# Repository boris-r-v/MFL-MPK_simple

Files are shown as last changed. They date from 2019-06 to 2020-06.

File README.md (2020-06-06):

# MFL-MPK_simple
Модем работающий по 2-х проводной физической линии связи на базе микросхемы FX604D4 - V23 совместимым модемом

**Задачи**
        
        Принять пакет данных по кодовой линии RS-232/485 и переслать этот пакет данных по физической линии
        Приянть пакет из физической линии и переслать на последовательный интерфейс RS-232/485
        
*Информация от уволившегося разработчика*

        MFL-MPK_simple

        Модем по RS-232 и RS-485 может работать на 4 скоростях: 19200, 38400, 57600, 115200. Скорость задается двумя битами на переключателе (вроде 7 и 8 переключатели). Остальные 6 переключателей – адрес модема. RS-232 и RS-485 работают одновременно.

        Запрос адреса: в RS-232 двумя байтами – 0x14, 0xFF. Ответ, два байта: 0xEB, 0x(адрес).

        Формат кадра на линии: 
            1) Заголовок (4 байта): 0x55, 0x(ст. байт размера данных), 0x(мл. байт размера данных), 0x(CRC8 заголовка)
            2) Данные из RS-485 и RS-232.

            В проекте гитигнор неправильно прописан, поэтому куча мусора. Зато в MFL-MPK_simple/dist/default/production есть hex-файл, он должен быть рабочим. Можно им прошить модем и проверить на стенде.

            Насчет коэф. усиления в линии. В его регулировке смысла не увидел, на макете линии в довольно больших диапазонах ее длины норм работает (до 8 км смотрел при самой плохой линии). Можно еще раз испытать. Сори, не помню и никуда не записал, какой поставил резистор (который задает коэф усил) на промышленной. Вроде 10 (или 100) кОм. Лучше проверить.

            Сама прошивка работает по принципу: от прерывания запускается процесс приема из линии (RS) и после приема сразу передается в RS (линию). line_to_RS и RS_to_line соответственно.

            Прошу еще раз проверить работу.

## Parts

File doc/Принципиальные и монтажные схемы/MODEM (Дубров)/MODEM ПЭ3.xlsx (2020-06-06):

Поз.обозначение | Наименование |  | Кол-во | Примечание
 | Конденсаторы
C1, C2 | К73-17-400-1.5 10% имп. | TS0200(2G155K)SB0G0R P:22.5mm | 2
C3 | CC0805KRX7R9BB154 | 0805 X7R 0.15uF ±10% 50V | 1
C4, C5 | CC1206KKX7R8BB225 | 1206 X7R 2.2uF ±10% 25V | 2
C6 | CC0805JRNPO9BN101 | 0805 NP0 100pF ±5% 50V | 1
C7, C17, C20 | T491B106K016AT | чип тант.16В 10мкФ 10% B | 3
C8, C9 | CC0805JRNPO9BN200 | 0805 NP0 20pF ±5% 50V | 2
C11-C16, C18, C19, C21-C29, C32, C34, C36 | CC0805ZRY5V9BB104 | 0805 Y5V 0.1uF +80/-20% 50V | 20
C31 | SH050M0220B5S-1012 | 50V 220uF /10*12/105° | 1
C35 | T491D476K025AT | чип тант.25В 47мкФ 10% D | 1
 | Микросхемы
DA1 | LM258DT |  | 1
DA2 | MC78L08ABDR2G |  | 1
DA3 | L78L33ABD |  | 1
DA4 | TEN 3-2413WIN-HI |  | 1
DD1 | FX604D4 |  | 1
DD2 | CMX868D2 |  | 1
DD3 | PIC24HJ128GP502 |  | 1
DD4, DD5 | ST3485EBDR |  | 2
DD6 | ST3232BDR |  | 1
DD7 | SN74HC165D |  | 1
 | Диоды
HL1, HL2, HL3 | KP-3216EC |  | 3
VD1 | SM6T6V8CA |  | 1
VD2 | BAV199 |  | 1
VD3, VD4 | SMAJ15CA |  | 2
VD5-VD10 | SMAJ5.0CA |  | 6
VD11 | SS14 |  | 1
VD12 | SMCJ30CA |  | 1
 | Транзисторы
VT1, VT2 | BCR135E6327 |  | 2
 | Резисторы
R1 | RC1206FR-07200RL | 1206 200 1% | 1
R2 | RC0805FR-0727KL | 0805 27.0K 1% | 1
R3, R7 | RC0805FR-0747K5L | 0805 47.5K 1% | 2
R4, R8 | RC0805FR-0724KL | 0805 24.0K 1% | 2
R5, R9 | RC0805FR-0712KL | 0805 12.0K 1% | 2
R6, R10 | RC0805FR-076K04L | 0805 6.04K 1% | 2
R11, R23-R31 | RC0805FR-0747KL | 0805 47.0K 1% | 10
R12 | RC0805FR-07150KL | 0805 150K 1% | 1
R13 | RC0805FR-07100KL | 0805 100K 1% | 1
R14, R15 | RC0805FR-07180RL | 0805 180 1% | 2
R16, R18, R19, R21 | RC0805FR-07560RL | 0805 560 1% | 4
R17, R20 | RC0805FR-07120RL | 0805 120 1% | 2
R22 | RC1206FR-071K5L | 1206 1.50K 1% | 1
RV1 | JVR10N180M87PU5 |  | 1
RV2 | JVR10N390K87PU5 |  | 1
 | Коммутация
SA1, SA2 | DHN-08F-V |  | 2
X1, X2 | 25.338.3753.0 | 8113_S/07 | 2
X1', X2' | 25.322.3753.0 | 8113_S/07 | 2
X3 | PLS-06 |  | 1
X4 | PBS-12 |  | 1
X4' | PLH-12-15mm |  | 1 | PLH-40-15mm
 | Прочее
FU1 | TRF250-120 |  | 1
FU2 | RXEF075 |  | 1
L1, L2 | MMZ2012Y202B |  | 2
L3, L4 | DLW5BTN102SQ2L |  | 2
L5 | UU10LF-B682 | 6.8mH 0.43A | 1
TV1 | LM-NP-1001-B1L |  | 1
ZQ1 | 3.579545 MHz | HC-49/US | 1 | ЧИП И ДИП

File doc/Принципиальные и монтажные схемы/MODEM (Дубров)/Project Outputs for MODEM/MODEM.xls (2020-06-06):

Comment | Description | Designator | Footprint | LibRef | Quantity
1.5uF |  | C1, C2 | TS02-22.5 | CC1206 | 2.0
0.15uF |  | C3 | CC0805 | CC1206 | 1.0
1.5uF |  | C4, C5 | CC1206 | CC1206 | 2.0
100pF |  | C6 | CC0805 | CC1206 | 1.0
10uF |  | C7, C17, C20 | SMB | SR-6 | 3.0
20pF |  | C8, C9 | CC0805 | CC1206 | 2.0
0.1uF |  | C11, C12, C13, C14, C15, C16, C18, C19, C21, C22, C23, C24, C25, C26, C27, C28, C29, C32, C34, C36 | CC0805 | CC1206 | 20.0
SH050M0220B5S-1012 |  | C31 | SH050-1019 | SR-6 | 1.0
47uF |  | C35 | SMD | SR-6 | 1.0
LM258DT |  | DA1 | LM258DT | LM258DT | 1.0
MC78L08ABDR2G |  | DA2 | L78L06ABD | L78L06ABD | 1.0
L78L33ABD |  | DA3 | L78L06ABD | L78L33ABD | 1.0
TEN 3-2413WIN-HI |  | DA4 | TEN3-2412WIN | TEN3-2412WIN | 1.0
FX604D4 |  | DD1 | FX604D4 | FX604D4 | 1.0
CMX868D2 |  | DD2 | CMX868D2 | CMX868D2 | 1.0
PIC24HJ128GP502 |  | DD3 | PIC24HJ128GP502 | PIC24HJ128GP502 | 1.0
ST3485 |  | DD4, DD5 | SP3485 | SP3485 | 2.0
ST3232BDR |  | DD6 | ST3232BDR | SP3232 | 1.0
SN74HC165D |  | DD7 | SN74HC165D | SN74HC165D | 1.0
TRF250-120 |  | FU1 | TRF250-120 | TRF250-120 | 1.0
RXEF075 |  | FU2 | RXEF075 | TRF250-120 | 1.0
KP-3216EC |  | HL1, HL2, HL3 | KP-3216EC | KP-3216EC_L | 3.0
MMZ2012Y202B |  | L1, L2 | MMZ2012Y202B | MMZ2012Y202B | 2.0
DLW5BTN102SQ2L |  | L3, L4 | DLW5BTN | DLW31SN | 2.0
UU10LF |  | L5 | UU10LF | TRANS | 1.0
200 |  | R1 | RC1206 | RC1206 | 1.0
27K |  | R2 | RC0805 | RC0805 | 1.0
47.5K |  | R3, R7 | RC0805 | RC0805 | 2.0
24K |  | R4, R8 | RC0805 | RC0805 | 2.0
12K |  | R5, R9 | RC0805 | RC0805 | 2.0
6.04K |  | R6, R10 | RC0805 | RC0805 | 2.0
47K |  | R11, R23, R24, R25, R26, R27, R28, R29, R30, R31 | RC0805 | RC0805 | 10.0
150K |  | R12 | RC0805 | RC0805 | 1.0
100K |  | R13 | RC0805 | RC0805 | 1.0
180 |  | R14, R15 | RC0805 | RC0805 | 2.0
560 |  | R16, R18, R19, R21 | RC0805 | RC0805 | 4.0
120 |  | R17, R20 | RC0805 | RC0805 | 2.0
1.5K |  | R22 | RC1206 | RC0805 | 1.0
JVR10N180M87PU5 |  | RV1 | JVR07N330 | JVR14N361 | 1.0
JVR10N390K87PU5 |  | RV2 | JVR07N330 | JVR14N361 | 1.0
DHN-08F-V |  | SA1, SA2 | DHN-08F-V | DHN-08F-V | 2.0
LM-NP-1001 |  | TV1 | LM-NP-1001 | LM-NP-1001 | 1.0
SM6T6V8CA |  | VD1 | SM6T6V8CA | SM6T6V8CA | 1.0
BAV199 |  | VD2 | BAV199 | BAV199 | 1.0
SMAJ15CA |  | VD3, VD4 | SMAJ6.0CA | SMAJ6.0CA | 2.0
SMAJ5.0CA |  | VD5, VD6, VD7, VD8, VD9, VD10 | SMAJ6.0CA | SMAJ6.0CA | 6.0
SS14 |  | VD11 | SS14 | SS14 | 1.0
SMCJ30CA |  | VD12 | SMCJ28A | SM6T6V8CA | 1.0
BCR135 |  | VT1, VT2 | BCR135 | BCR135 | 2.0
8113_S/07 |  | X1, X2 | 8113_S/07 | 8113_S/07 | 2.0
PLS-06 |  | X3 | PLS-06 | PLS-06 | 1.0
PLS-12 |  | X4 | PLS-12 | PLS-12 | 2.0
3.58M |  | ZQ1 | HC-49/S | ZQ | 1.0

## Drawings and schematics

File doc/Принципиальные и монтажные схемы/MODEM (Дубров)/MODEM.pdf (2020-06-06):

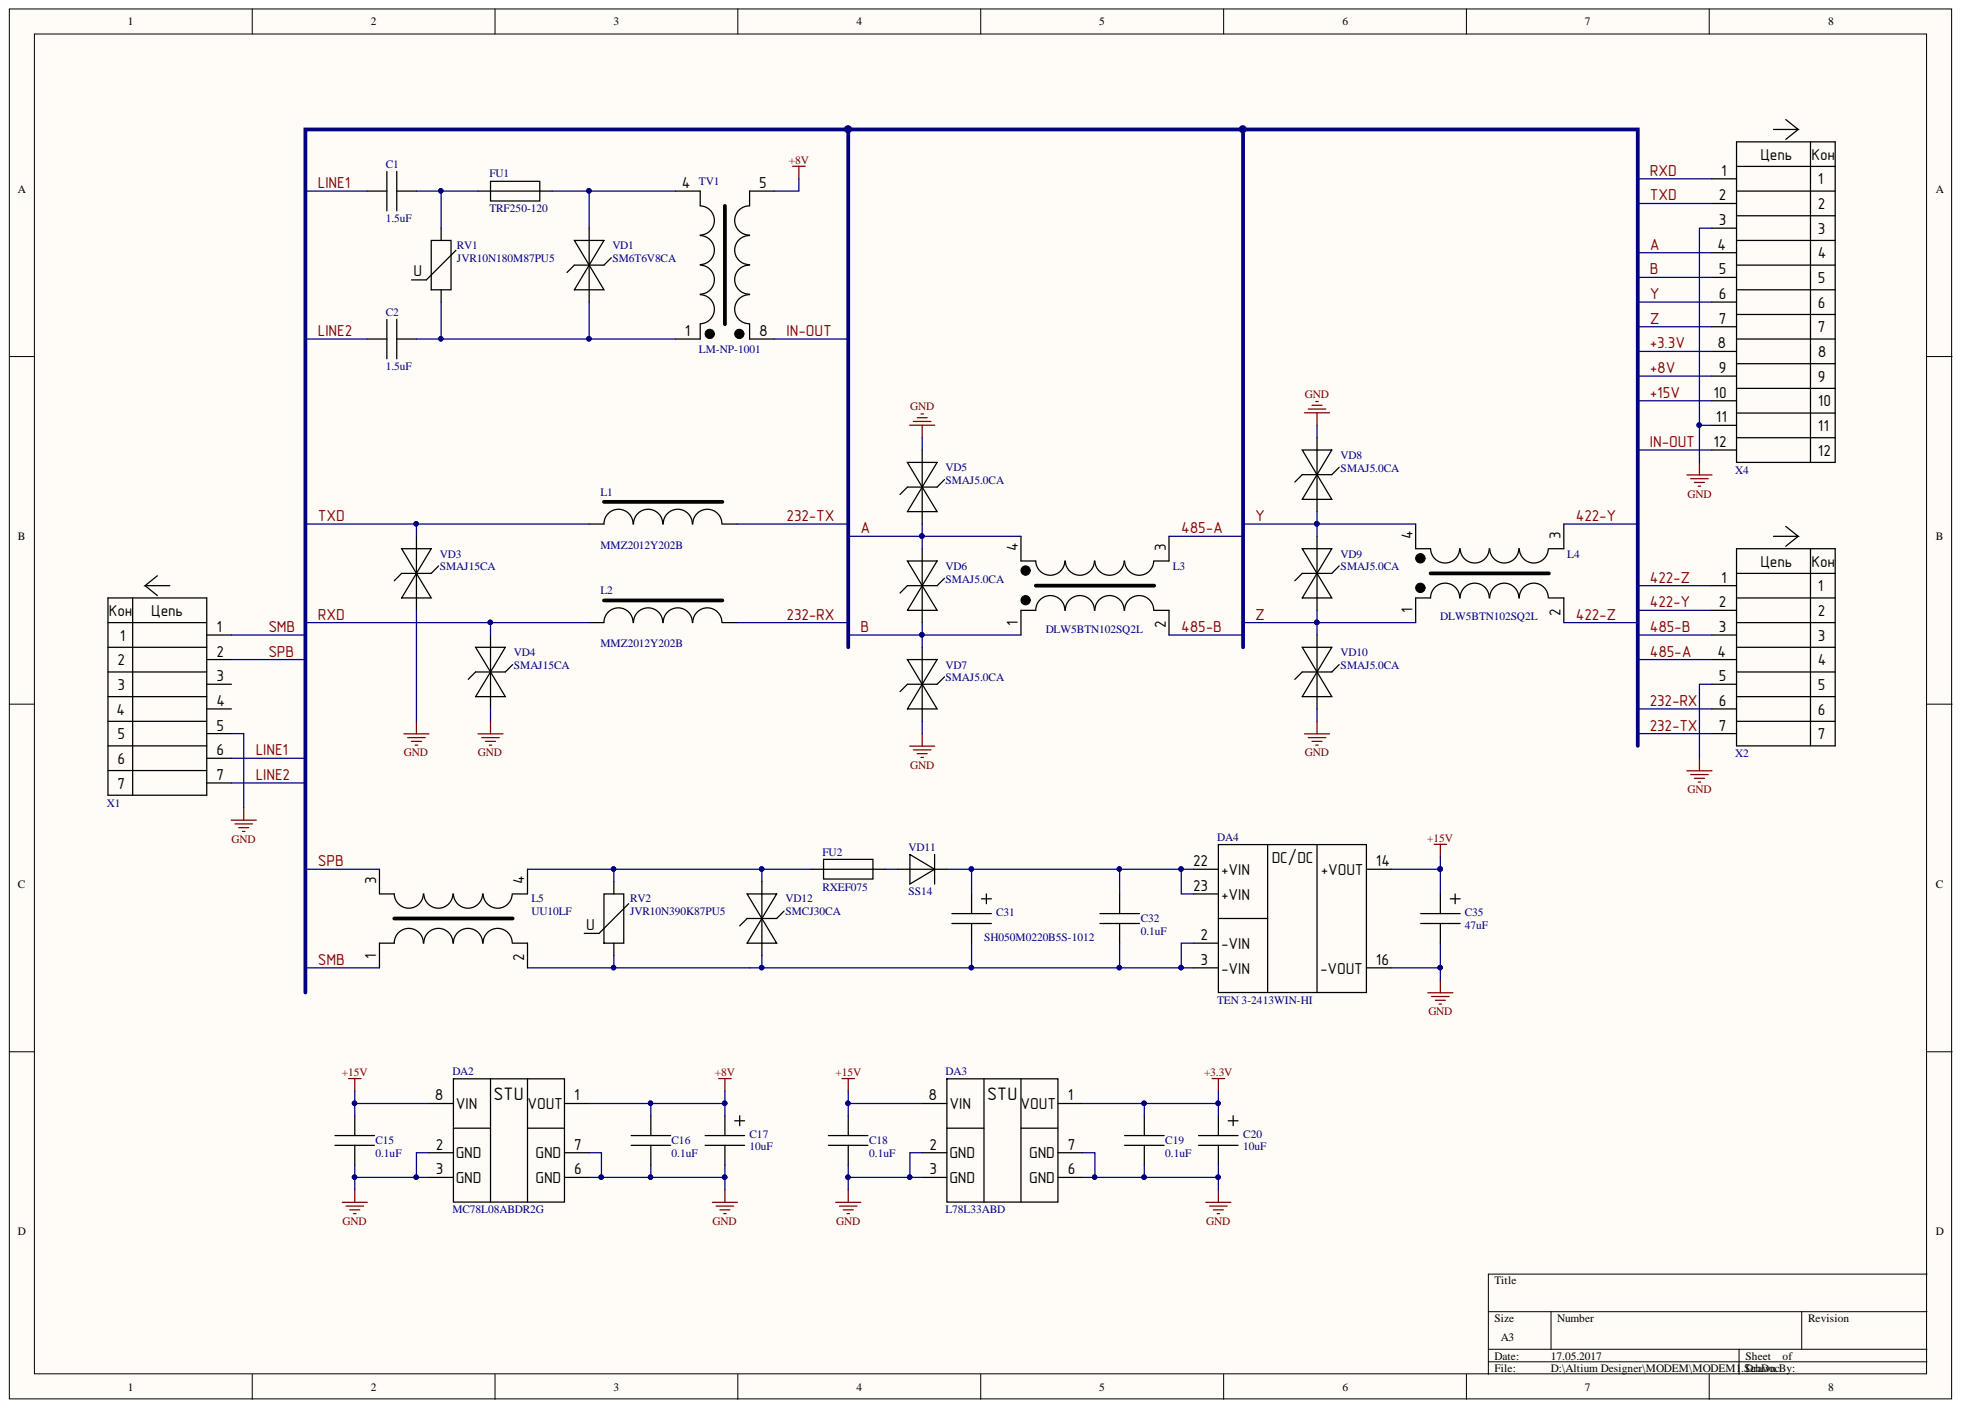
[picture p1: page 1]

+ 3.3 V | | 8
+ 8 V | | 9
+ 1 5 V | | 1 0
IN -O U T | | 1 1

1 0
1 1
1 2

6 | 7 | LIN E 2 | N N N G N D

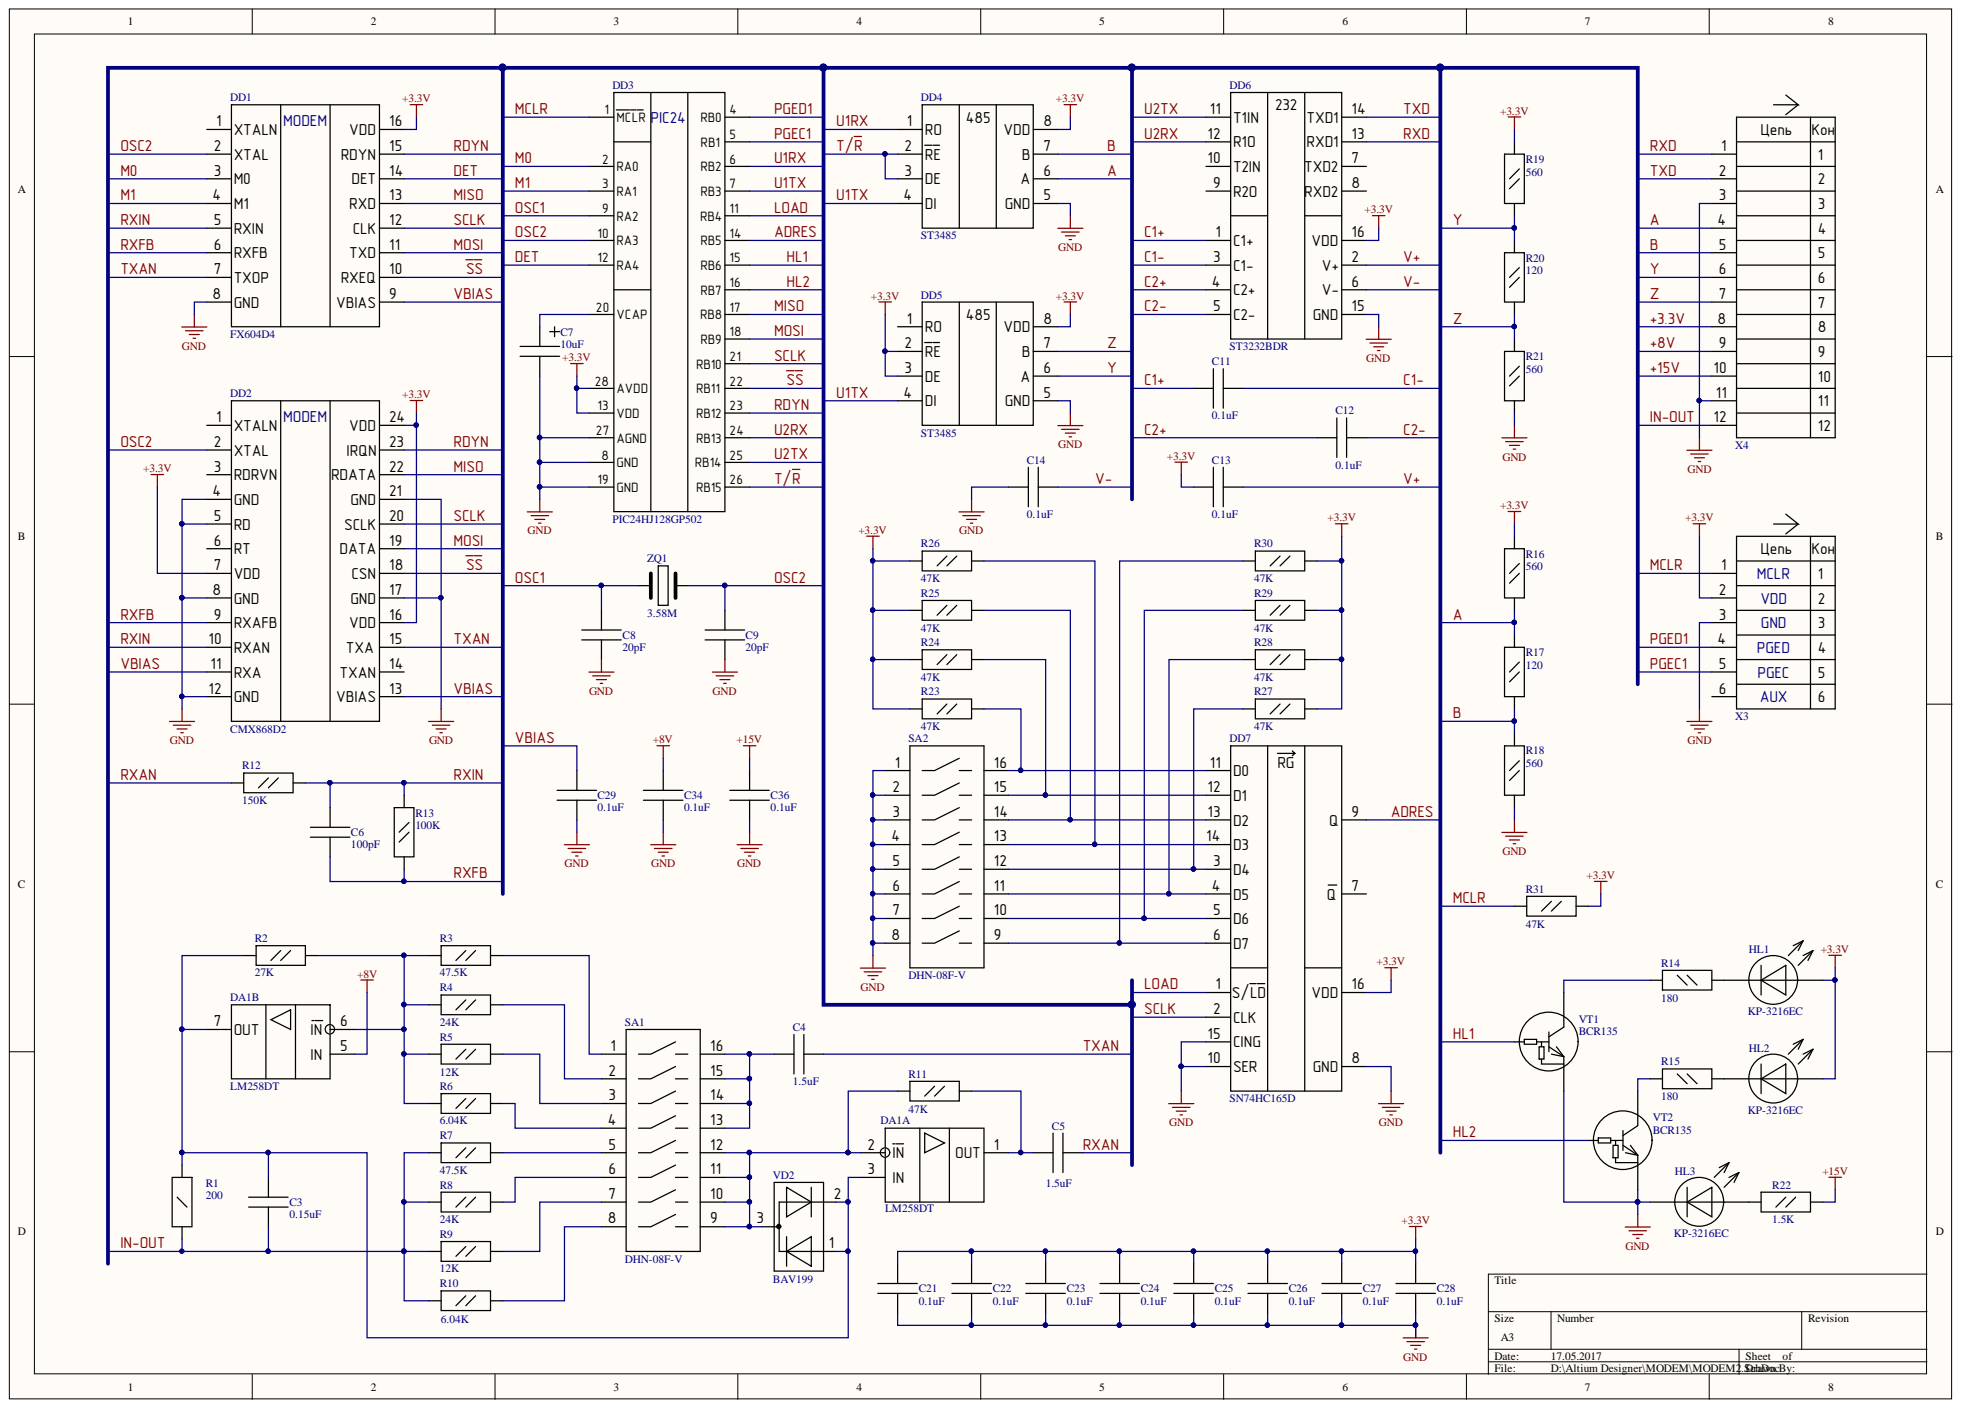
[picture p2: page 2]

Цепь | Кон
MCLR | 1 1

PGED | 4 4
PGEC | 5 5
AUX | 6 6

5 | 12 | | | D4 3
6 | 11 | | D5 4
7 | 10 | | D6 5
8 | 9 | | D7 6

RXFB

TXAN | LOAD | S/LD 1

2 | 15 | R11
3 | 14

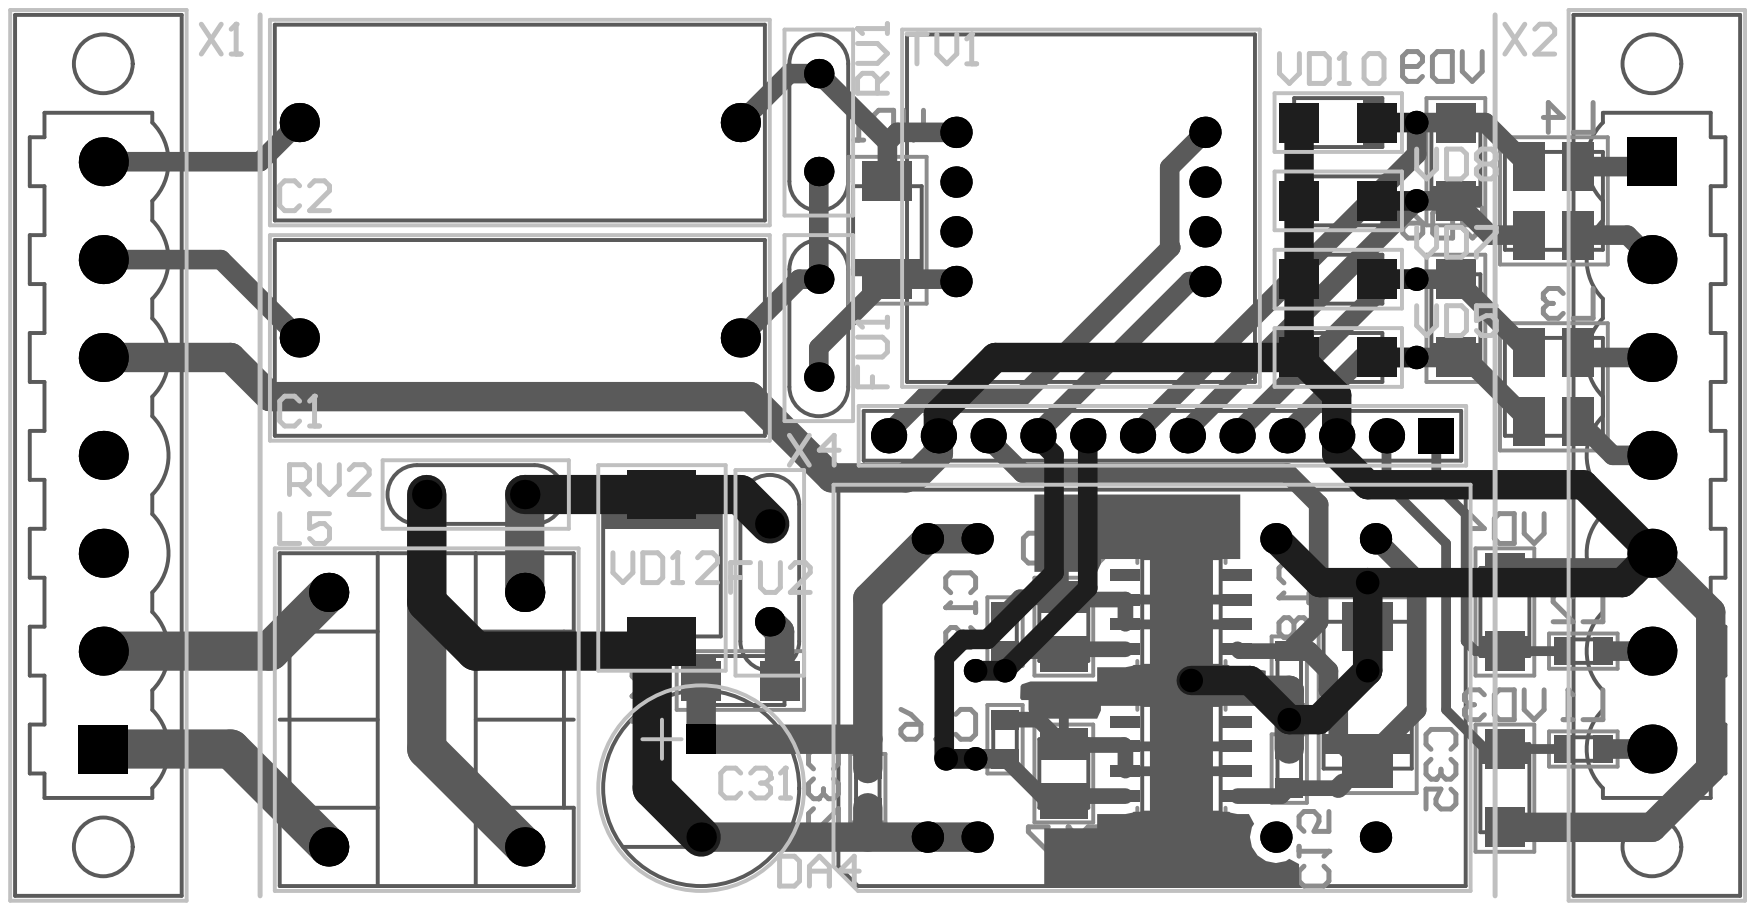
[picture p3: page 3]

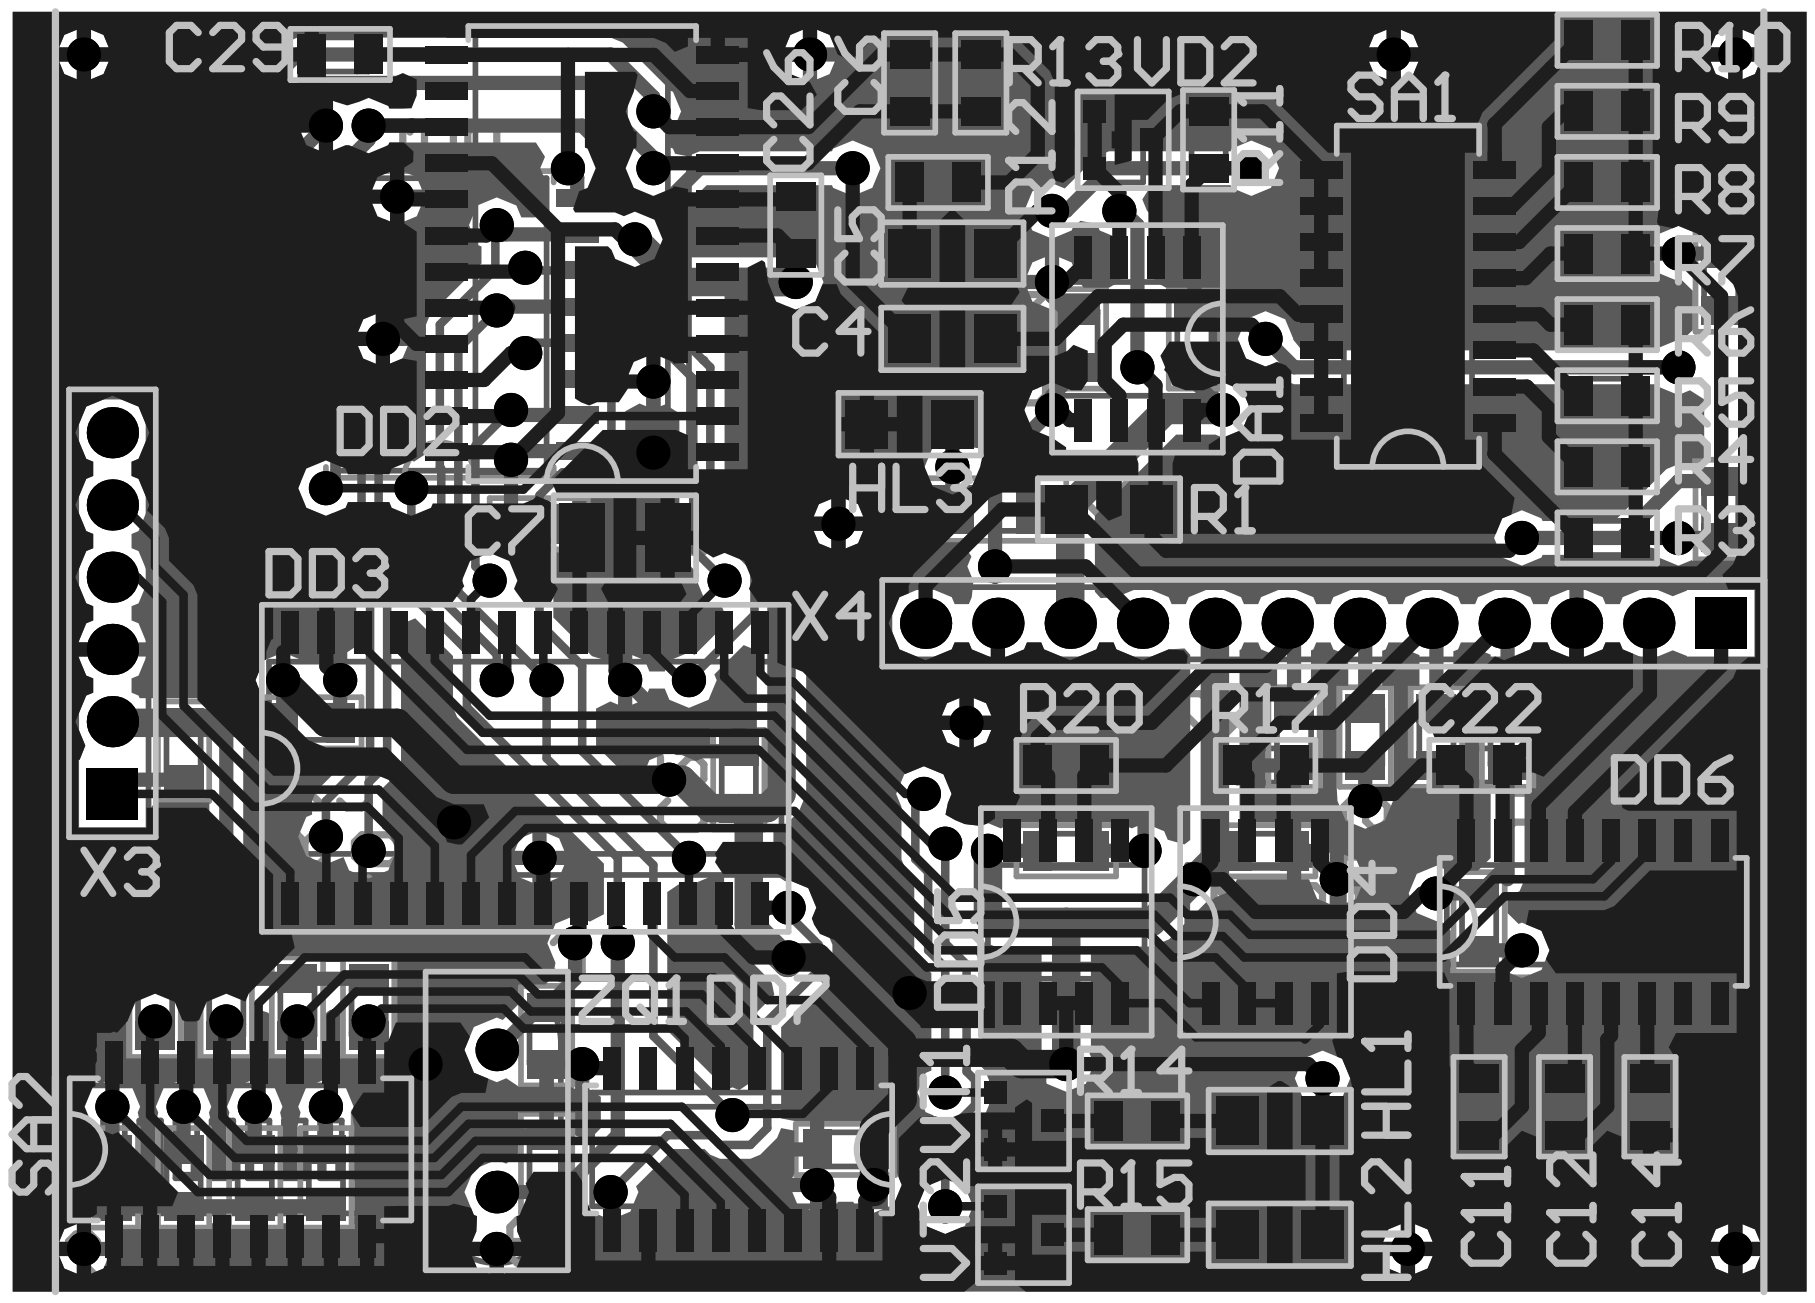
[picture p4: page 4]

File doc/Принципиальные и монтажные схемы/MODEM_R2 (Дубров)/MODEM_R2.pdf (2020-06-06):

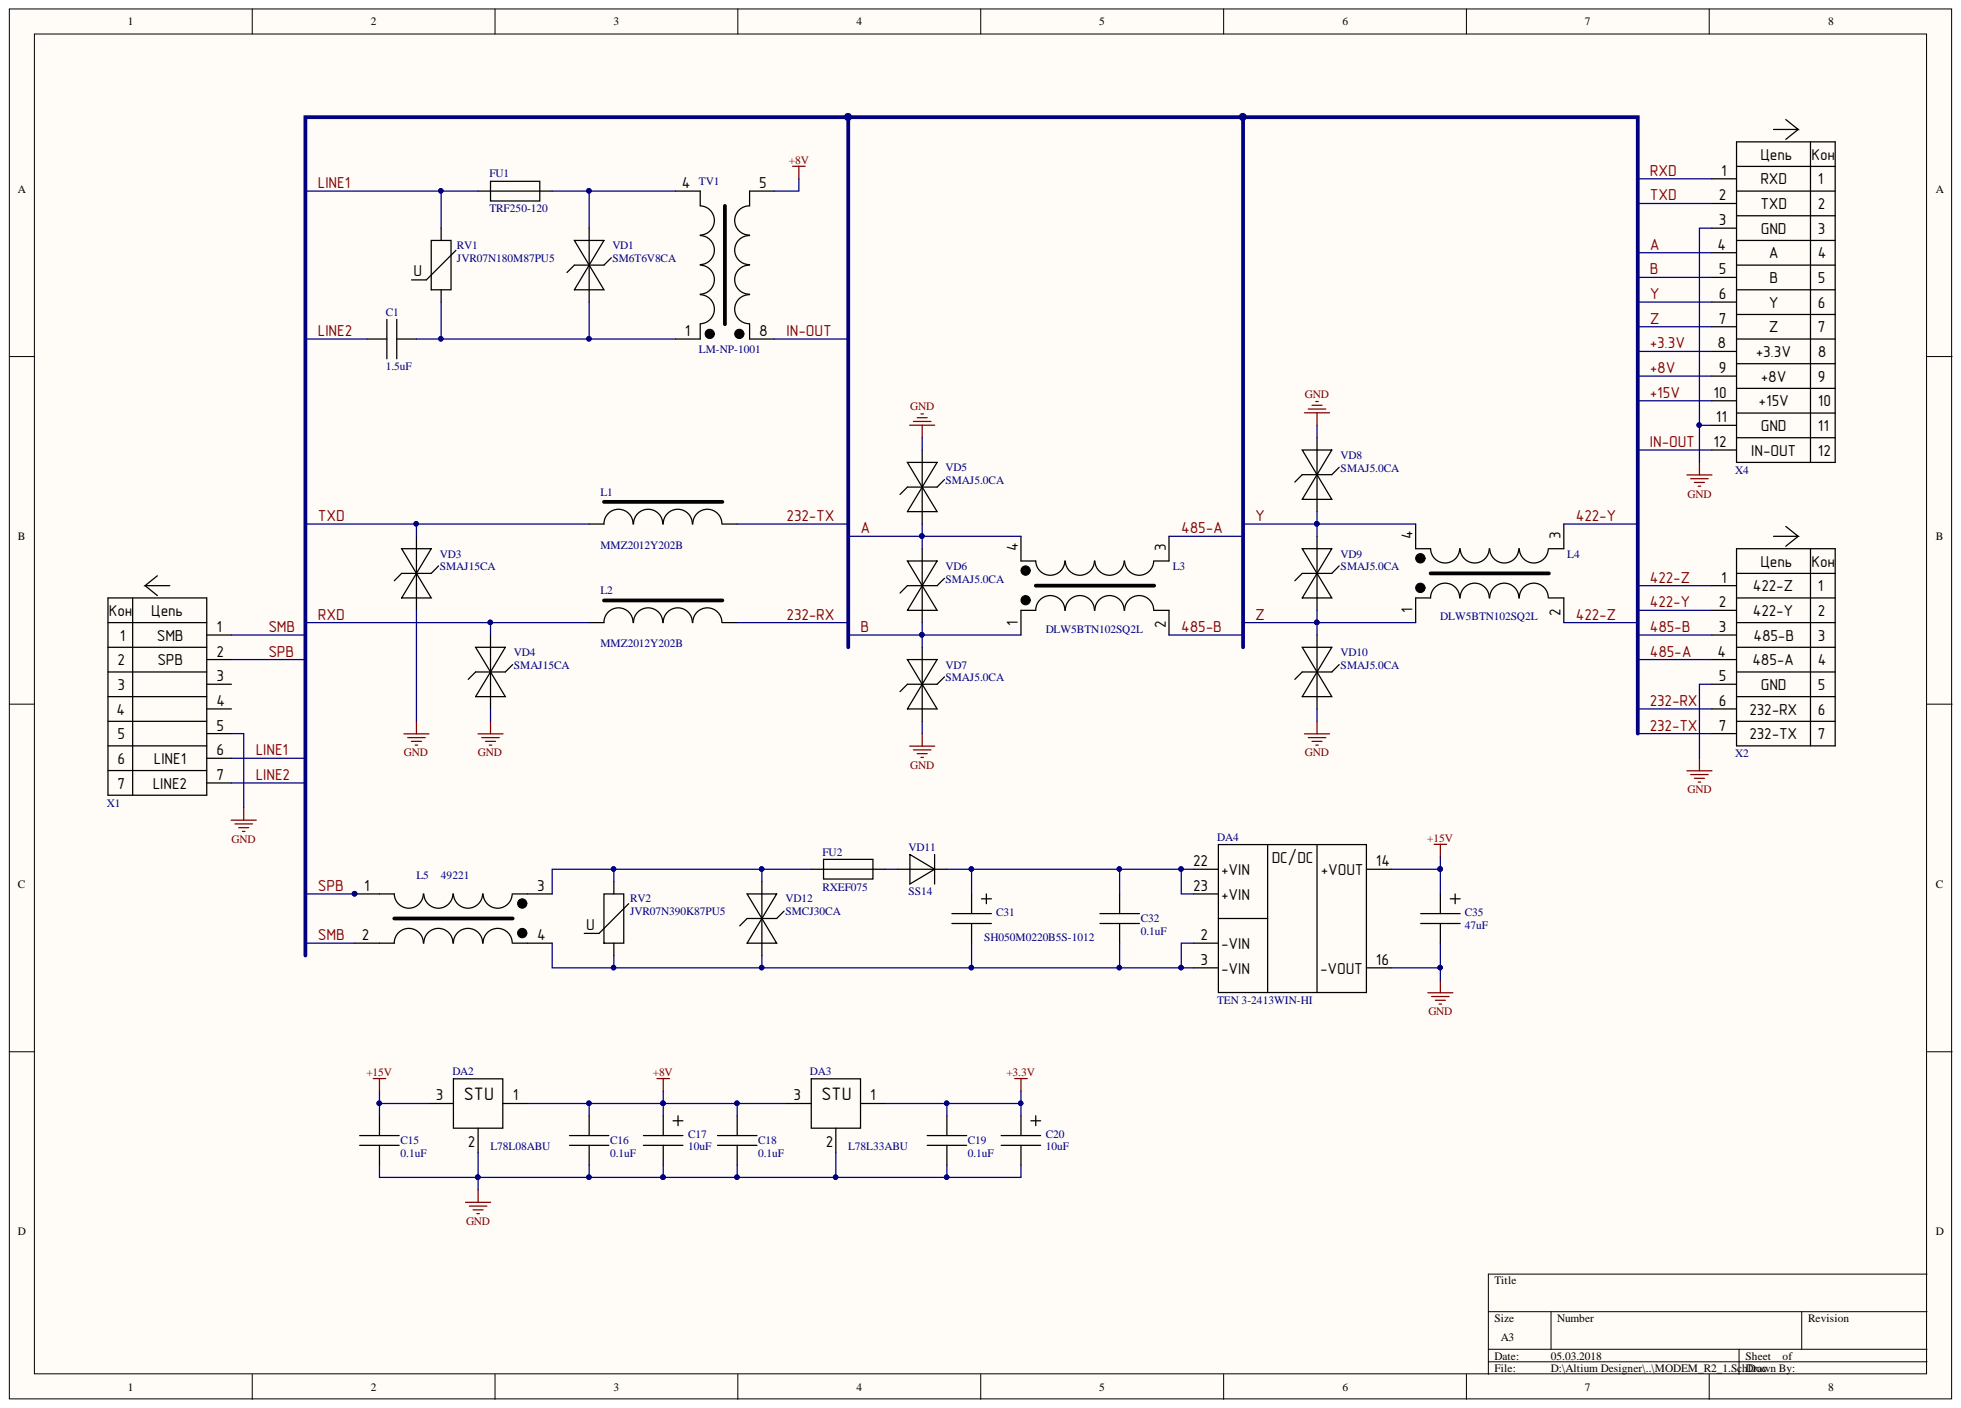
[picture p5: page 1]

+8V | GND | GND

Цепь | Кон
RXD | 1 1
TXD | 2 2
GND | 3 3
A | 4 4
B | 5 5
Y | 6 6
Z | 7 7

+3.3V
+8V
+15V

+8V | 9 9
+15V | 10 10
GND | 11 11
IN-OUT | 12 12

IN-OUT

422-Z | 1 1

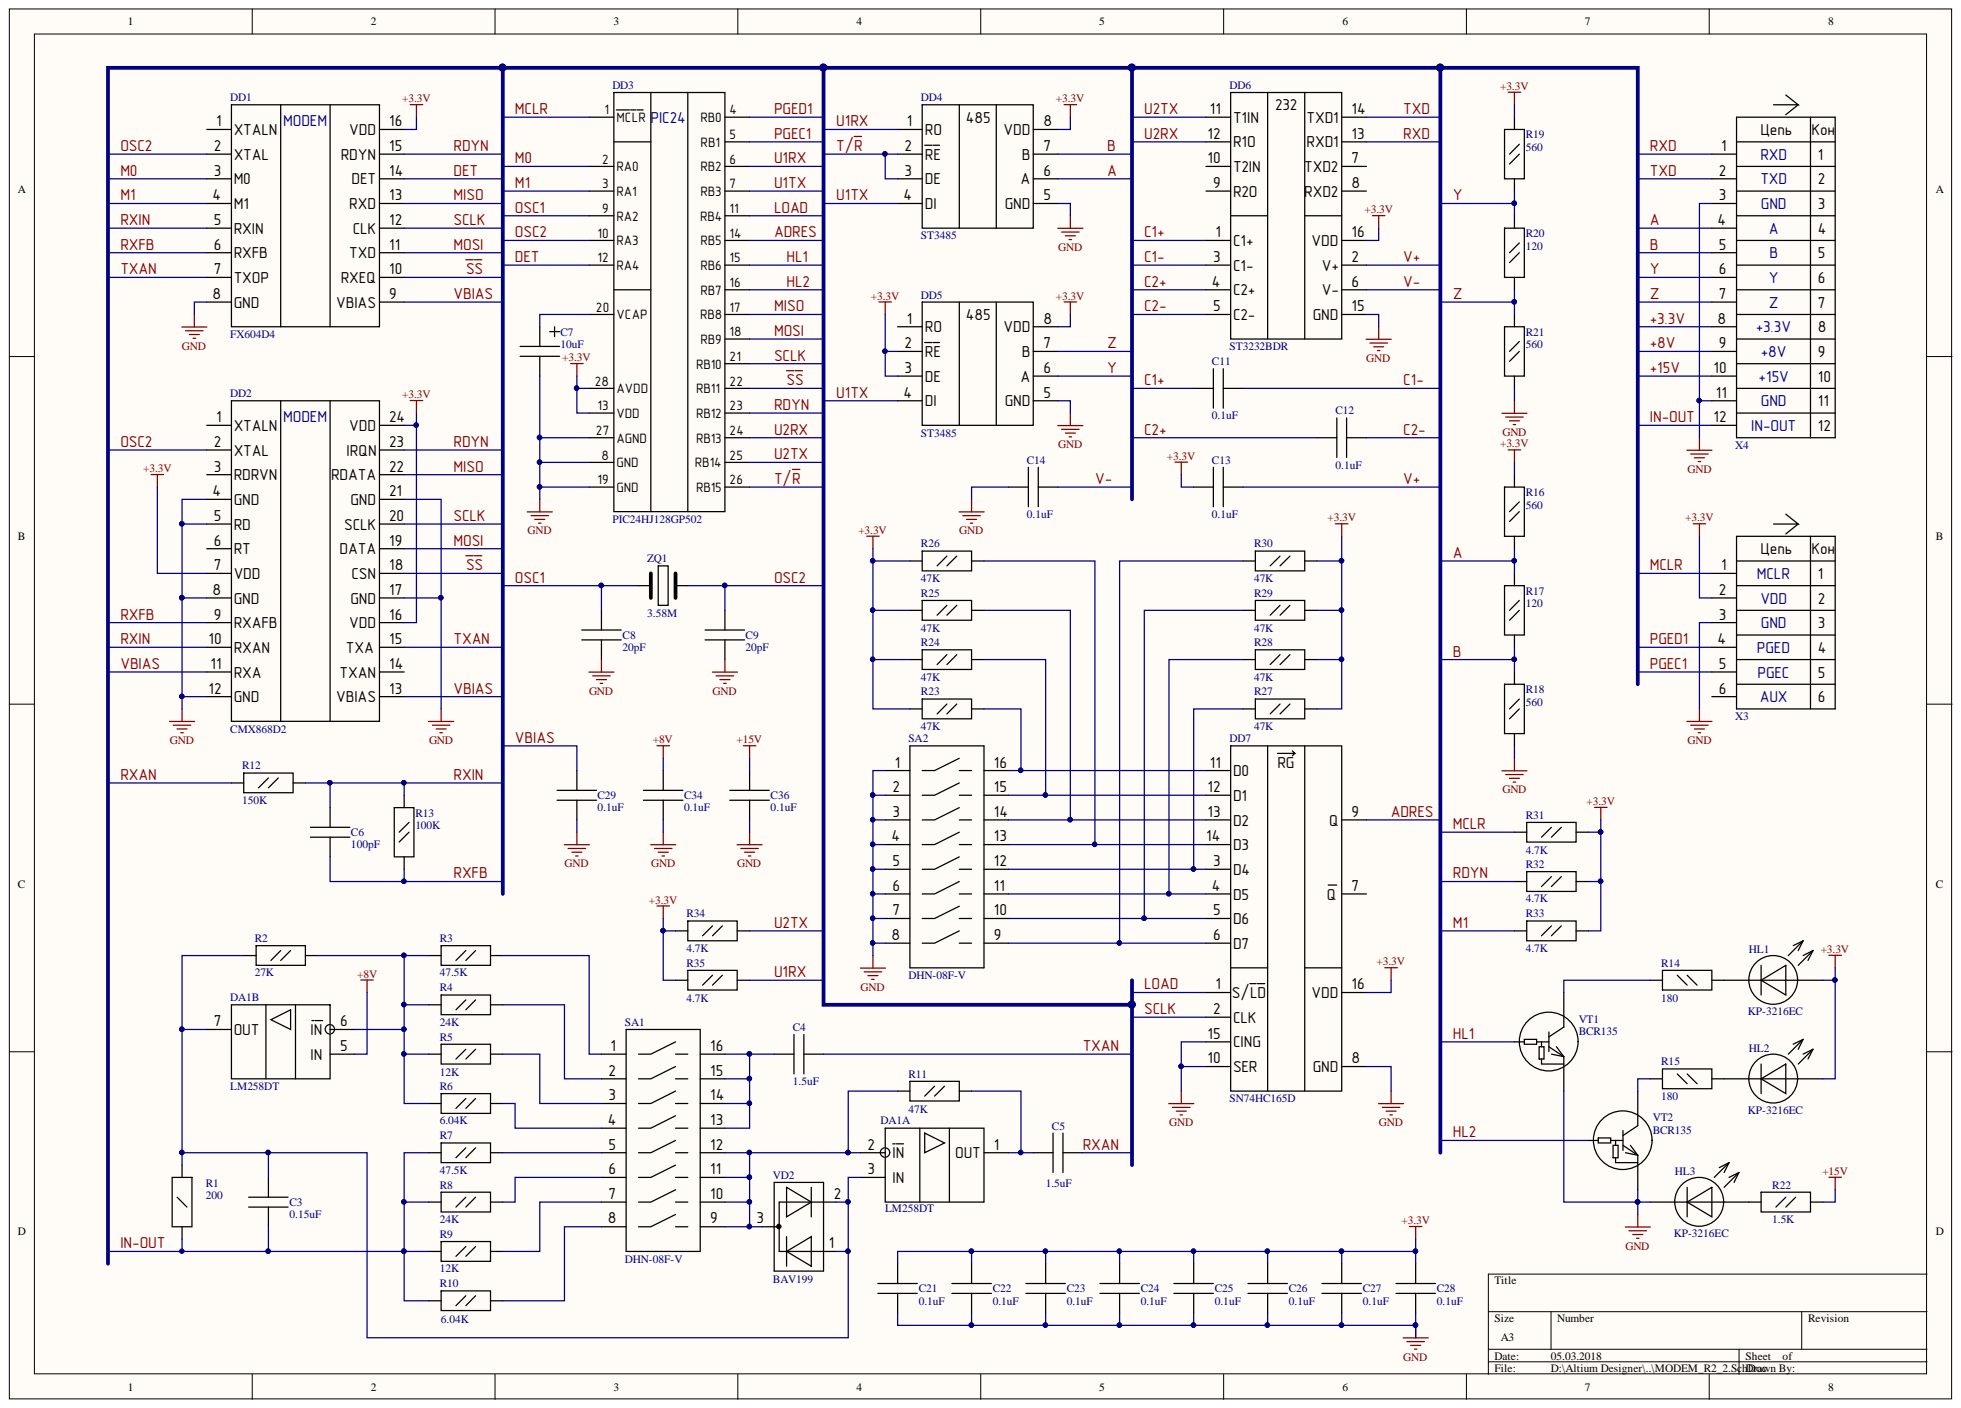
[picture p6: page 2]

Цепь | Кон
MCLR | 1 1

PGED | 4 4
PGEC | 5 5
AUX | 6 6

2 | 15 | D1 12
3 | 14 | D2 13

RXFB | +3.3V

2 | 15 | R11
3 | 14

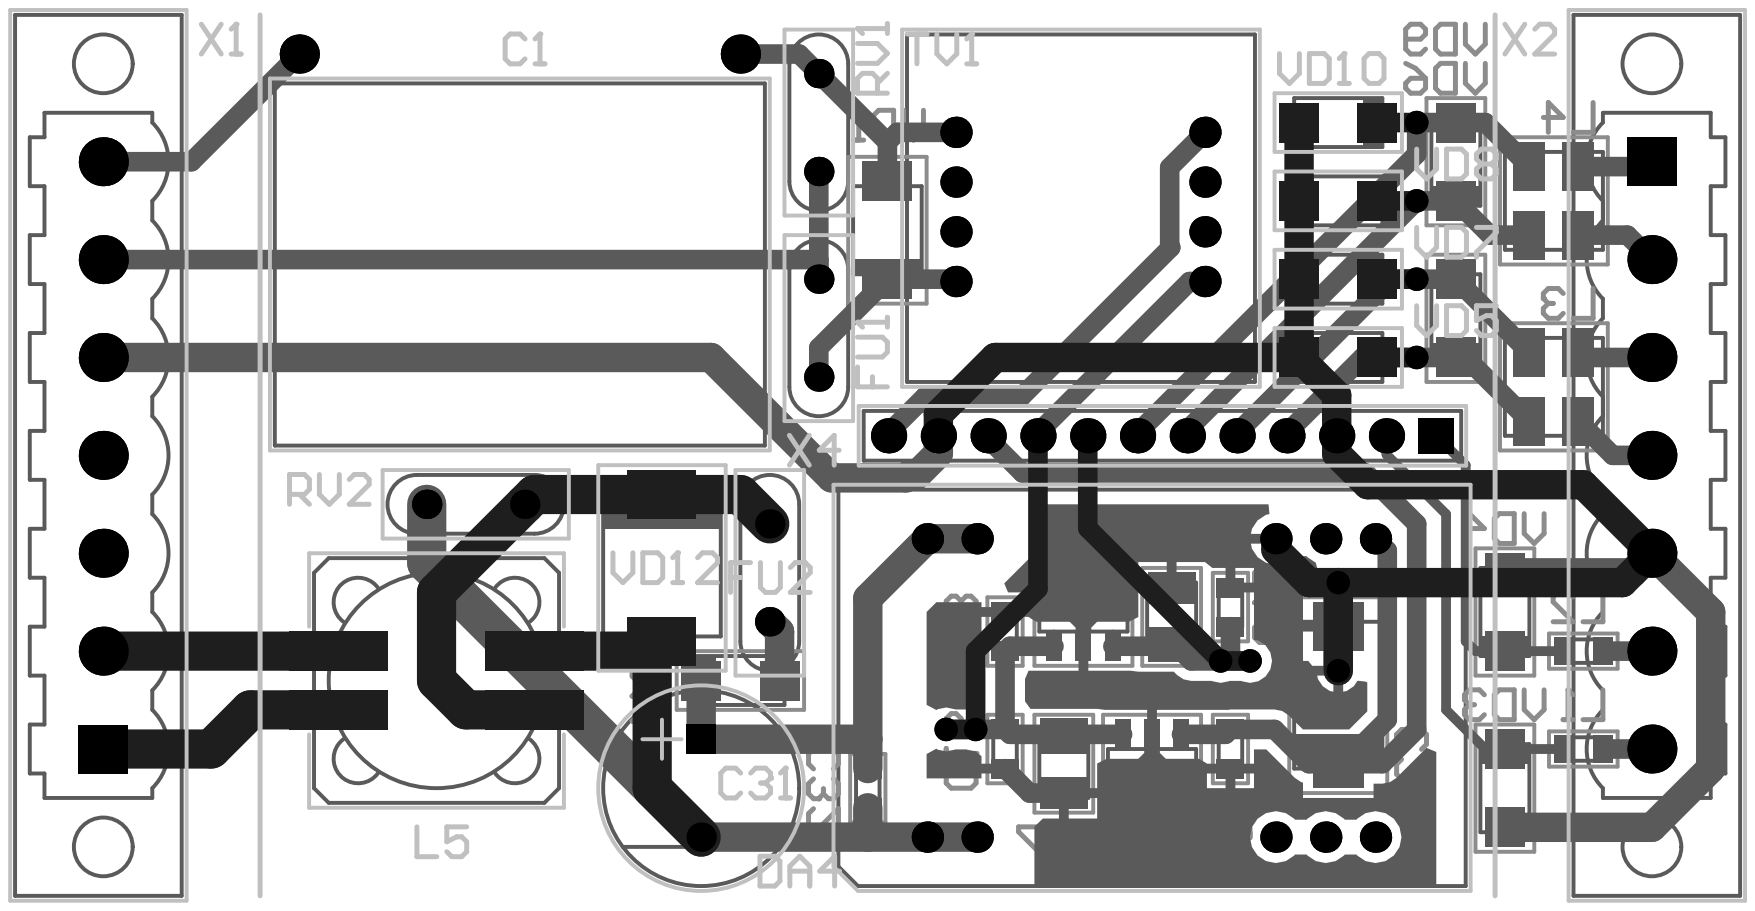
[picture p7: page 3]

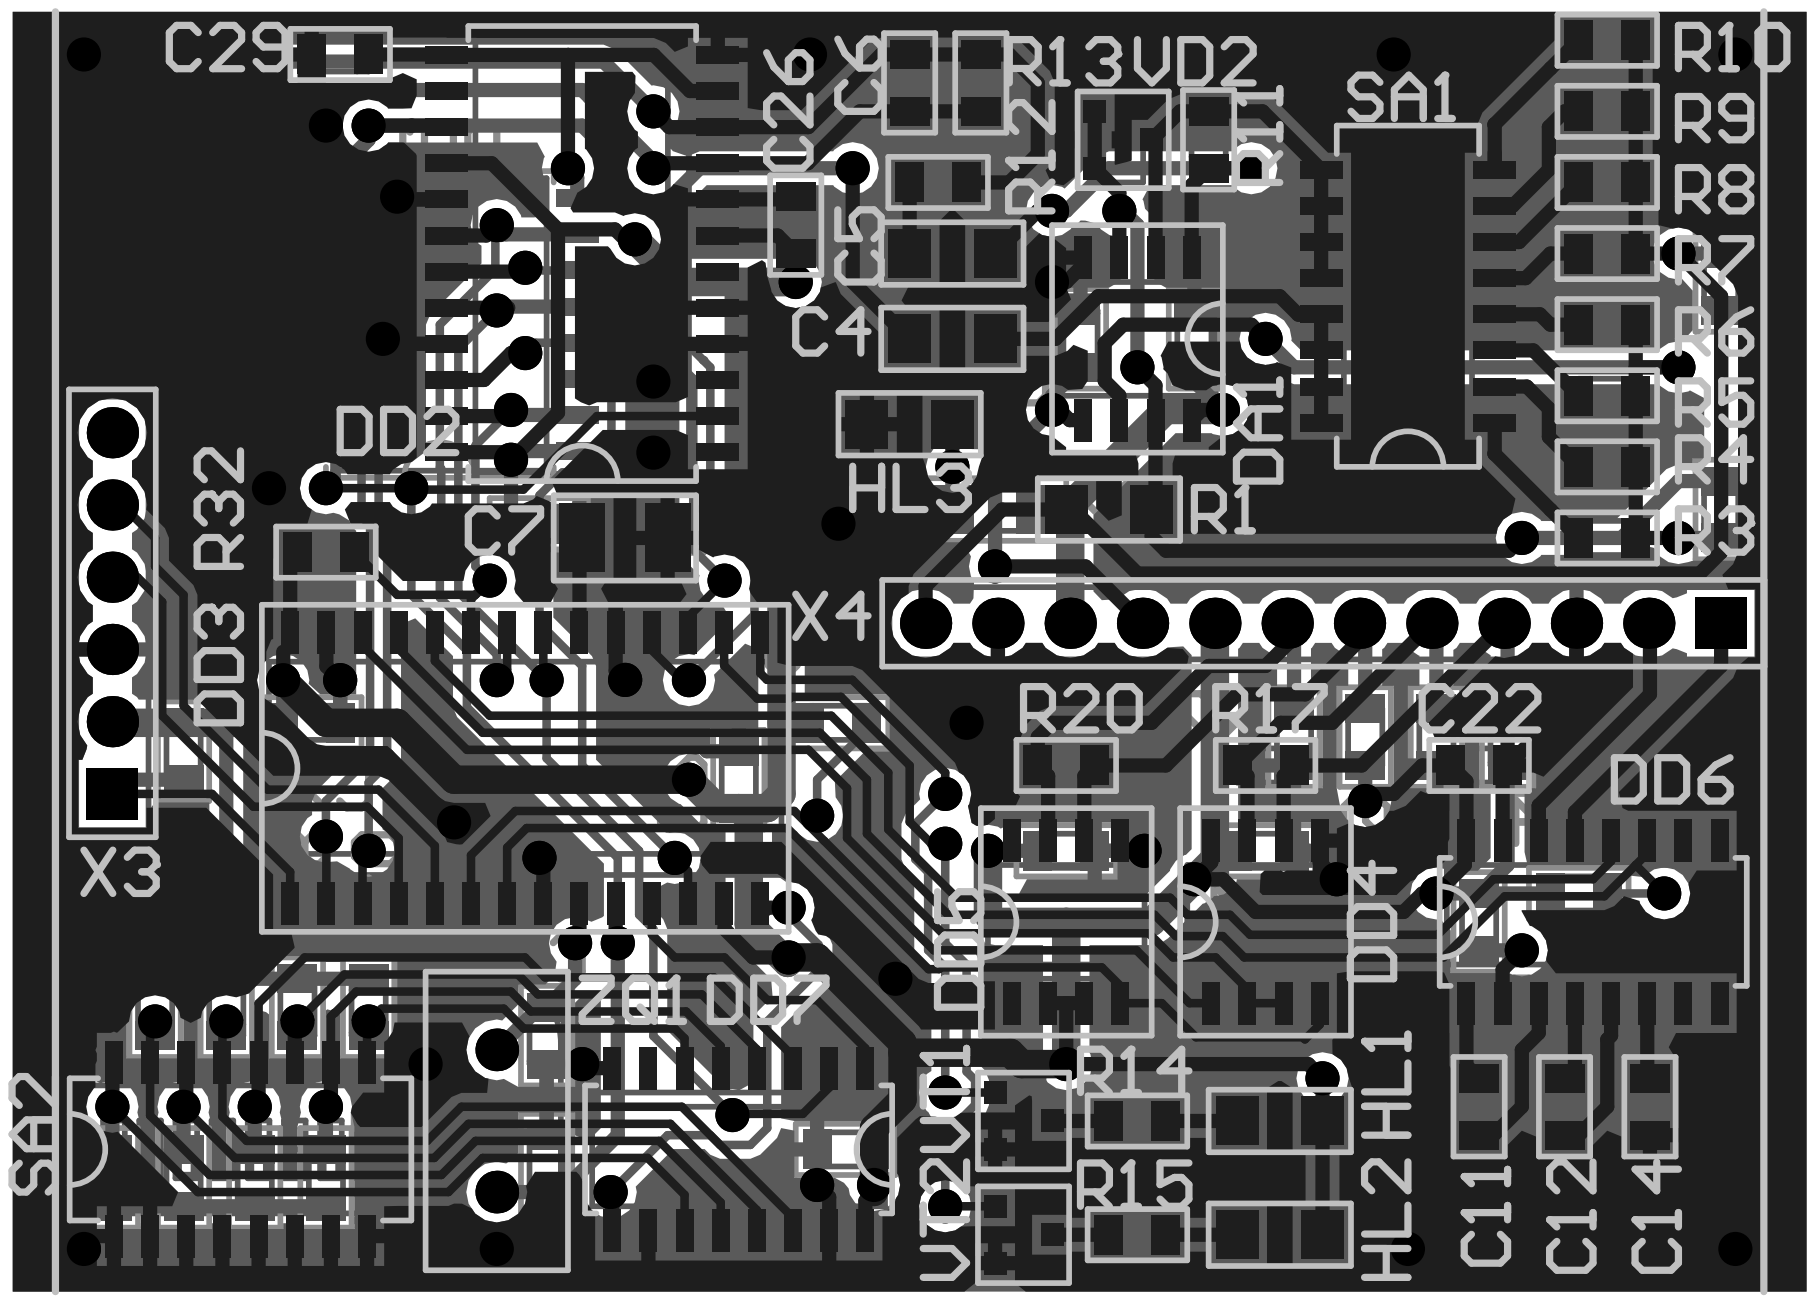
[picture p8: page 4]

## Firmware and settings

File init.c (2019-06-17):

#include "init.h"

static void init_osc(void); //инициализация генератора частоты
static void remap(void); //ремапинг
static void init_address_baudrate(void); //инициализация адреса/скорости модема
static void init_ports(void); //инициализация портов (настройка на вход-выход)
static void init_timer(void); //инициализация таймера1 (настройка времени), отвечает за время после окончания передачи, при переполнении таймера считаем, что байт с RS принят полностью
static void init_UART1(void);  // RS-485
static void init_UART2(void);  // RS-232

static uint8_t get_baudrate(void);

static struct ADDRBAUDRATEBITS
{

    union
    {
        uint8_t addr_baudrate;

        struct
        {
            unsigned addr : 6;
            unsigned baudrate : 2;
        };
    };
} ADDRBAUDRATEbits;

void init_modem()
{
    init_osc(); //инициализация генератора частоты
    remap(); //ремапинг
    init_ports(); //инициализация портов (настройка на вход-выход)
    init_address_baudrate(); //инициализация адреса/скорости модема
    init_UART1();
    init_UART2();
    init_timer(); //инициализация таймера1 (настройка времени)
    
    RX_FX604;
    TX_RS485 = 0;
}

/* Настройка генератора (частота Fcy)       НЕ ЗАБУДЬ ПОМЕНЯТЬ В "common.h" SYSCLK
Fosc = Fin * M/(N1*N2), Fcy = Fosc/2,                       
Fosc = 3579545 * 64/(2*8) = 14318180 Hz
Fcy = 14318180/2 = 7159090 Hz */
static void init_osc(void)
{
    PLLFBD = 62; // M = 64,   M = PLLFBD + 2
    CLKDIVbits.PLLPRE = 0; // N1 = 2
    CLKDIVbits.PLLPOST = 3; // N2 = 8
    OSCTUN = 0; // настройка FRC генератора
    RCONbits.SWDTEN = 0; // отключение WDT
    while (0 == OSCCONbits.LOCK); // ждем, пока установится частота
    return;
}

// Ремап ножек

static void remap(void)
{
    __builtin_write_OSCCONL(OSCCON & ~(1 << 6)); // разрешение ремапа

    RPINR18bits.U1RXR = 2; // U1RX на 6 ногу (RP2)
    RPOR1bits.RP3R = 3; // U1TX на 7 ногу (RP3)

    RPINR19bits.U2RXR = 13; // U2RX на 24 ногу (RP13)
    RPOR7bits.RP14R = 5; // U2TX на 25 ногу (RP14)

    __builtin_write_OSCCONL(OSCCON | (1 << 6)); // запрещение ремапа
    return;
}

// Инициализация адреса

static void init_address_baudrate(void)
{
    int8_t clk = 7;

    SCLK = 0;
    LOAD = 1;
    LOAD = 0;
    LOAD = 1;

    ADDRBAUDRATEbits.addr_baudrate = 0;
    ADDRBAUDRATEbits.addr_baudrate = ADDRBAUDRATEbits.addr_baudrate | (ADRES << clk);

    for (clk = 6; clk >= 0; --clk)
    {
        SCLK = 1;
        SCLK = 0;
        ADDRBAUDRATEbits.addr_baudrate = ADDRBAUDRATEbits.addr_baudrate | (ADRES << clk);
    }
    ADDRBAUDRATEbits.addr_baudrate ^= 0xFF; //инвертируем биты, т.к. включенный переключатель подтягивает к нулю 
}

// RS-485

void init_UART1(void)
{
    switch (get_baudrate())
    {
    case BAUDRATE_19200:
        U1BRG = BAUDRATE_19200_BRG;
        break;
    case BAUDRATE_38400:
        U1BRG = BAUDRATE_38400_BRG;
        break;
    case BAUDRATE_57600:
        U1BRG = BAUDRATE_57600_BRG;
        break;
    case BAUDRATE_115200:
        U1BRG = BAUDRATE_115200_BRG;
        break;
    default:
        break;
    }

    U1MODE = 0;
    U1MODEbits.BRGH = 1; // высокоскоростной режим UART
    U1MODEbits.STSEL = 0; // один стоповых бита

    U1STA = 0;
    U1STAbits.URXISEL = 0; // прерывание от приемника после каждого принятого байта
    
    U1MODEbits.UARTEN = 1; // включение модуля UART
    U1STAbits.UTXEN = 1; // разрешение на передачу UART
}

//RS-232

void init_UART2(void)
{
    switch (get_baudrate())
    {
    case BAUDRATE_19200:
        U2BRG = BAUDRATE_19200_BRG;
        break;
    case BAUDRATE_38400:
        U2BRG = BAUDRATE_38400_BRG;
        break;
    case BAUDRATE_57600:
        U2BRG = BAUDRATE_57600_BRG;
        break;
    case BAUDRATE_115200:
        U2BRG = BAUDRATE_115200_BRG;
        break;
    default:
        break;
    }

    U2MODE = 0;
    U2MODEbits.BRGH = 1; // высокоскоростной режим UART
    U2MODEbits.STSEL = 0; // один стоповых бита
    
    U2STA = 0;
    U2STAbits.URXISEL = 0; // прерывание от приемника после каждого принятого байта
        
    U2MODEbits.UARTEN = 1; // включение модуля UART
    U2STAbits.UTXEN = 1; // разрешение на передачу UART
}

static void init_ports(void)
{
    AD1PCFGL = 0xFFFF; //все порты на цифровой режим
    M1 = 1; 
    M0 = 0;
    
    LATBbits.LATB14 = 1; //RB14 (U2TX), передача в RS-232
    LATBbits.LATB3 = 1; //RB3 (U1TX), передача в RS-485, нужно выставить "1", т.к. между настройкой на вывод и включением UARTa не должно быть нуля
    TX_RS485 = 0;
    
    TRISAbits.TRISA0 = 0; //RA0 (M0) на выход, M0 - прием/передача FX604
    TRISAbits.TRISA1 = 0; //RA1 (M1) на выход, M1 - прием/передача FX604
    TRISAbits.TRISA4 = 1; //RA4 (DET) на вход, детектор несущей в линии
    TRISBbits.TRISB2 = 1; //RB2 (U1RX) на вход, UART1 - прием от RS-485
    TRISBbits.TRISB3 = 0; //RB3 (U1TX) на выход, UART1 - передача в RS-485
    TRISBbits.TRISB4 = 0; //RB4 (LOAD) на выход, LOAD - нужен для сдвигового регистра, который определяет положение переключателей SA2
    TRISBbits.TRISB5 = 1; //RB5 (ADRES) на вход, ADRES - к выходу сдвигового регистра, который определяет положение переключателей SA2
    TRISBbits.TRISB6 = 0; //RB6 (HL1) на выход, HL1 - светодиод
    TRISBbits.TRISB7 = 0; //RB7 (HL2) на выход, HL2 - светодиод
    TRISBbits.TRISB8 = 1; //RB8 (MISO) на вход, MISO данные с линии
    TRISBbits.TRISB9 = 0; //RB9 (MOSI) на выход, MOSI данные в линию
    TRISBbits.TRISB10 = 0; //RB10 (SCLK) на выход, SCLK - частота к модему FX604 и к сдвиговому регистру
    TRISBbits.TRISB11 = 0; //RB11 (SS) на выход, SS - подключена к RXEQ модема FX604, это включение фильтра для приемника
    TRISBbits.TRISB12 = 1; //RB12 (RDYN) на вход, RDYN - Ready for Data Transfer, готовность передать данные с линии
    TRISBbits.TRISB13 = 1; //RB13 (U2RX) на вход, UART2 - прием от RS-232
    TRISBbits.TRISB14 = 0; //RB14 (U2RX) на вход, UART2 - передача в RS-232
    TRISBbits.TRISB15 = 0; //RB15 (T/R) на выход, T/R - настройка на передачу/прием драйвера RS-485 (1 - передача в RS-485; 0 - прием)

    SS = 1; //включение фильтра для приемника FX604
}


static void init_timer(void)
{
    
    switch (get_baudrate())
    {
    case BAUDRATE_19200:
        PR1 = TIMEOUT_FOR_19200;
        break;
    case BAUDRATE_38400:
        PR1 = TIMEOUT_FOR_38400;
        break;
    case BAUDRATE_57600:
        PR1 = TIMEOUT_FOR_57600;
        break;
    case BAUDRATE_115200:
        PR1 = TIMEOUT_FOR_115200;
        break;
    default:
        break;
    }
}
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

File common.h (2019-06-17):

#ifndef COMMON_DRIVER_H
#define COMMON_DRIVER_H

#define SYSCLK              14318180                         //частота Fosc
#define FCY                 SYSCLK/2


#define BAUDRATE_19200      0
#define BAUDRATE_38400      1
#define BAUDRATE_57600      2
#define BAUDRATE_115200     3

#define BAUDRATE_19200_BRG  ((FCY/19200)/4) - 1
#define BAUDRATE_38400_BRG  ((FCY/38400)/4) - 1
#define BAUDRATE_57600_BRG  ((FCY/57600)/4) - 1
#define BAUDRATE_115200_BRG ((FCY/115200)/4) - 1




//******************************************************************************                                          
//*                          НОЖКИ МИКРОКОНТРОЛЛЕРА                            *
//******************************************************************************
#define HL1                 LATBbits.LATB6
#define HL2                 LATBbits.LATB7
#define M0                  LATAbits.LATA0
#define M1                  LATAbits.LATA1
#define DET                 PORTAbits.RA4
#define RX_FX604            M1 = 1; M0 = 0; __delay_ms(4);                   //настройка модема на прием
#define TX_FX604            M0 = 1; M1 = 0; __delay_us(200);                //настройка модема на передачу
#define MISO                PORTBbits.RB8
#define MOSI                LATBbits.LATB9
#define RDYN                PORTBbits.RB12
#define SCLK                LATBbits.LATB10
#define TX_RS485            LATBbits.LATB15
//пины, связанные с адресом модема
#define ADRES               PORTBbits.RB5
#define LOAD                LATBbits.LATB4
#define SS                  LATBbits.LATB11


//                                          КОНСТАНТЫ
// временные промежутки для FX604
#define Ts_us               1
#define Th_us               1
#define Td_us               1
#define Tchi_us             1


#define BUFF_SIZE           2048
#define SIZE_OF_HEAD        3
#define NULL_BYTE           0
#define DATA_SIZE_H         1
#define DATA_SIZE_L         2

// константы для таймера
#define TIMEOUT_FOR_19200     (16*FCY)/19200            // если время превышает время принятия 16 бит - то считаем, что пакет полностью принят
#define TIMEOUT_FOR_38400     (16*FCY)/38400
#define TIMEOUT_FOR_57600     (16*FCY)/57600
#define TIMEOUT_FOR_115200    (16*FCY)/115200



#include <stdint.h>
#include <string.h>
#include <stdbool.h>
#include <stdlib.h>
#include <xc.h>
#include <libpic30.h>

typedef struct
{
    uint8_t* ptr;
    uint16_t len;
    uint16_t cnt;
} data;

typedef struct
{
    uint8_t null_byte;
    uint16_t data_size;
    uint8_t CRC8;
    uint8_t data_buffer[BUFF_SIZE];
} frame;

#endif // COMMON_DRIVER_H
